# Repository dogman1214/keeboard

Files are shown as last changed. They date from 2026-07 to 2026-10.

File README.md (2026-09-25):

# keeboard

###Note for FORGE Reviewers:
I had already bought the parts for this keyboard. I'm looking for reimbursment, not funding, if that is possible (I beg of thee it is).
I'm sorry that the prices for everything is so high. If you review the BOM, nothing would really be buildable without all the parts I bought. I tried to find the cheapest parts, but I realized that shipping minimum is $8, so then ordering from multiple 3rd party websites, prices would stack up considerably. So then I chose to order from Amazon. Please don't be taken aback by the price, I tried to make it as cheap as possible. The total price was just under $300. 
Please understand why I spent so much. First of all, Trump. Ordering the PCB from JLCPCB costed $45 or so dollars for the bare pcb. Then shipping costs came in, and then also tarrifs. that more than doubled the price to $100, but with the in ap $20 discount I reduced it to $80.
But all these microbumps and macrobumps in price really increased how much I had to spend. Please understand me. I had viewed the budget to be like $180, but it was really concerning how much the price started increasing by. 
PLEASE PLEASE approve this review. I beg of thee. Of courser, changes might need to be made, and I'm fine with that. But on the long term I don't want to lose the money I invested in this project, I did ordered prematurely because Intially I was doing projects via Stardance, but I realized NO WAY i could make deadline. So I swapped to this :) also I know double dipping will get me banned. Don't even tempt me.  I fully swapped over to this.

BY THE WAY, I HAVE ALL THE RECIEPTS AND EVERYTHING SAVED!!! PM me on slack: raghavsharma1214 if you have any inquiries about why price is so high. or just anything.

I'll delete this rant once approved :)

## Overview

This is an ANSI104 layout keyboard. Meaning 100% size, full numpad, and everything. It has creamy gateron milky yellow pro v2 switches, and an esp32 controlling it all. Finally, it is a gasket mount to dampen vibrations, and a silicon pour for the same effect, and to add more weight.  

I created this keyboard because I wasn't really satisfied with the keyboards on the market, and the current keyboard I have now. I want to follow the aesthetic I want, and not some drab boring tech-grey color or whatever, while keeping my own physical case style as well. 

One unique thing i'm proud of is crafting my own Gasket mount system. Instead of using clunky o-ring systems, I designed a brand new board-wide poron tape design. Like foam, it works like a sandwitch above and below the keyboard plate, and designed to provide maximum creamieness.

Editable CAD file: https://drive.google.com/file/d/1waTcEkKPX5QRJGWGog04dOq1EIFDCUFI/view?usp=sharing
Uploading to drive due to the file been 500mb, too large to upload to github.

## Gallery:




## Future Improvements

Optimize the keyboard case design, maybe don't have as many bulky screws. Make the firmware better I guess, minimize latency so that I can game on it. Of course, the keyboard isn't physically built at the moment. 
---

## ASSEMBLY
### ** haven't built yet. Waiting for approval by FORGE **
1. Solder on the diodes and kailh hotswap sockets
2. Solder in the esp32
3. Plug in the switches, with the plate in the middle
4. place PORON foam in the gasket mounts sandwitch style
5. place the plate in between the gaskets
6. place heatset inserts in bottom and screw in m3 screws via the top
7. flash firmware
8. Pour in the silicon pour underneath the PCB, make sure to seal it off with seran wrap first.
9. enjoy!

# Bill of Materials (BOM)

### Electronics & Hardware

| Item | Description | Cost (Pre‑Tax) | Link |
| :--- | :--- | :--- | :--- |
| Switches | Gateron Milky Yellow Pro V2 | $25.90 | https://www.amazon.com/gp/product/B0C2CZJQHT |
| Rotary Encoder | ALPS EC11 THT 20k thread-blue vertical switch (H: 20mm) | $5.58 | https://mouser.com |
| Keycaps | PBT green, MOA profile | $24.99 | https://www.amazon.com/gp/product/B0F914Q43R |
| Diodes | 1N4148 SMD (Qty: 104), SOD‑123 | $0.18/unit | https://www.mouser.com/en/ProductDetail/Diodes-Incorporated/1N4148W-7-F |
| Stabilizers | Durock V3 screw‑in | $25.99 | https://www.amazon.com/dp/B0B2RW12S2 |
| PCB | Custom PCB | $45 | AIVON (with $30 discount applied) |
| Kailh Hotswap Sockets | 120 pcs | $13.20 | https://mechanicalkeyboards.com/products/kailh-switch-hot-swap-socket |
| ESP32‑S3 DevKitC‑1 (N16R8) | MCU | $8.99 | https://www.amazon.com/dp/B0GBT212KM |
| Cyanoacrylate Glue | CA super glue | $5.99 | https://www.amazon.com/dp/B0DYJPW9GK |

### Fasteners & Case Hardware

| Item | Description | Cost | Link |
| :--- | :--- | :--- | :--- |
| M3 Heatset Inserts | Brass | $6.99 | https://www.amazon.com/dp/B0FWWW8VP1 |
| M3 Screws | Assorted set | $6.99 | https://www.amazon.com/dp/B0D3X5CT2J |
| 3D Printed Case | Custom | — | — |
| 3D Printed Plate | Custom | — | — |
| 3D Printed Knob | EC11 compatible | — | — |
| Adhesive Transfer Tape | 3M Scotch 924 ATG | $9.57 | https://www.amazon.com/dp/B00FFDUG9M |

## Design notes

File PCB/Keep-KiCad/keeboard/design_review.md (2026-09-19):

# KiCad Design Review: keeboard

**Project**: keeboard  
**Schematic**: keeboard.kicad_sch  
**PCB**: keeboard.kicad_pcb  
**Analyzer**: kicad-happy v2.2.1  
**KiCad Version**: 10.0  

---

## 1. Power Tree Analysis

### Power Rails Detected
- **GND** — global ground, voltage: 0V (validated)

### Power Source Status ⚠️
- **3.3V rail (U1-3V3-Pad1)**: No declared source detected
  - No PWR_FLAG present
  - No regulator output mapping
  - No bridged solder jumper path to a sourced net
  - **Recommendation**: Add a PWR_FLAG to declare the rail as externally powered, or trace the rail back to a regulator output. If the source lives on another sheet, promote the net name to a global label.

- **5V rail (U1-5V-Pad21)**: No declared source detected
  - No PWR_FLAG present
  - No regulator output mapping
  - **Recommendation**: Add a PWR_FLAG or trace back to power input source.

### Power Flow Summary
The schematic currently has only a global GND net defined. The ESP32-S3-DevKitC's 3.3V and 5V power inputs lack explicit source declarations. For a keyboard with an ESP32-S3, power typically flows from a USB-C connector → voltage regulator → 3.3V/5V rails → ESP32 VCC and component VCC pins. Without a defined regulator or PWR_FLAG, the power tree is incomplete.

---

## 2. Net Tracing Summary

### Overall Statistics
- **Total nets**: 144
- **Total wires**: 327
- **Total no-connects**: 9
- **Unique components**: 218 (7 unique part types by value+footprint)

### Key Matrix Detection ✅
- **6×21 key matrix detected** (104 estimated keys)
- Matches the **ANSI-104** keyboard specification
- **Row nets**: ROW0, ROW1, ROW2, ROW3, ROW4, ROW5
- **Column nets**: COL0 through COL20 (21 columns)
- **104 diodes** (1N4148) connected in the matrix
- **104 switches** (matrix scan switches)

### Rotary Encoder ✅
- **SW1** — RotaryEncoder_Switch symbol present
- Footprint: `Rotary_Encoder:RotaryEncoder_Alps_EC11E-Switch_Vertical_H20mm`
- Also includes stabilizer: **S1** (MX_stab) with footprint `PCM_marbastlib-mx:STAB_MX_2u`
- Quadrature outputs and switch detected

### Wireless Module ✅
- **U1** — ESP32-S3-DevKitC detected
- Wireless type: WiFi/BLE
- Module correctly identified in netlist

### Component Breakdown
| Type | Count | Details |
|---|---|---|
| Diodes (1N4148) | 104 | Matrix common-cathode/common-anode configuration |
| Switches (SW_Push) | 98 | Matrix scan buttons + additional buttons |
| Switches (RotaryEncoder) | 1 | SW1 — rotary encoder with switch |
| Stabilizers (MX_stab) | 2+ | S1, S6 — Cherry MX-style stabilizers |
| IC (ESP32-S3) | 1 | U1 — WiFi/BLE module |

---

## 3. Design Verification

### ANSI-104 Keyboard Layout ✅ CONFIRMED
The key matrix detector found a **6×21 grid** = **104 keys**, exactly matching the ANSI-104 form factor. The row and column nets are properly named (ROW0-ROW5, COL0-COL20) and connected through 104 diodes.

### Rotary Encoder with Switch ✅ CONFIRMED
- SW1 present with RotaryEncoder_Switch value
- Includes both quadrature channels (A/B) and push-button switch
- Stabilizer S1 present for MX-style keycap support

### ESP32-S3-DevKitC ✅ CONFIRMED
- U1 correctly identified as ESP32-S3-DevKitC
- WiFi/BLE wireless module detected
- Pin mapping consistent with DevKitC footprint

### BOM & Sourcing ⚠️
- **0% MPN coverage** — all 7 unique BOM lines missing manufacturer part numbers
- Parts affected: 1N4148 diodes (104 pcs), RotaryEncoder_Switch (1 pc), SW_Push variants (98 pcs), ESP32-S3-DevKitC (1 pc)
- **Recommendation**: Populate MPN fields before fabrication. Use the digikey/mouser/lcsc skills to search by value/footprint.

### Datasheet Coverage ⚠️
- No `datasheets/` directory found
- No BOM parts have MPNs, so no datasheets can be extracted
- **Recommendation**: Run the datasheet sync skill (DigiKey/LCSC) or manually note all claims as "per symbol/library" until datasheets are attached.

### Electrical Rule Check (ERC) ⚠️
The ERC found several violations (see ERC.json), but many are expected for this design:

| Issue | Severity | Notes |
|---|---|---|
| Power pin not driven (#PWR01) | Error | Global power symbol not connected to source |
| CHIP_PU (U1 pin 3) not connected | Error | May be intentionally left floating or requires external pull-up |
| Multiple GPIO pins not connected | Error/Wireless modules often have unused pins |
| ROW/COL labels dangling | Error | Some labels may not connect to the matrix (verify netlist) |
| USB D+/D- not connected | Error | Only needed if USB functionality is used |

**Important**: Many "pin not connected" findings for ESP32 GPIOs are normal — not all 34+ GPIOs need to be connected. The critical ones to verify are: CHIP_PU (enable), USB D+/D-, and the power pins.

---

## 4. Caveats & Known Issues

### High Priority
1. **Power source not declared** — 3.3V and 5V rails lack PWR_FLAG or regulator mapping. The board will not power up without an external power source or regulator circuit.
2. **0% MPN coverage** — Board cannot be fabricated or assembled without manufacturer part numbers. Prototype ordering will fail BOM readiness checks.

### Medium Priority
3. **No datasheets available** — All electrical claims must be qualified as "per symbol/library" until datasheets are attached.
4. **ERC violations** — Several "pin not connected" and "label dangling" findings. Review each: some are expected (unused GPIOs), some need correction (power sources, matrix connections).

### Low Priority
5. **Lifecycle audit not run** — Component EOL/NRND status unknown. Run with `--lifecycle` flag when API keys are available.
6. **SPICE simulation not run** — Requires ngspice/LTspice for behavioral verification of filters, dividers, and the regulator loop.

---

## 5. Recommendations

1. **Add PWR_FLAG symbols** for 3.3V and 5V power rails, or add a voltage regulator circuit with feedback dividers properly connected.
2. **Populate MPN fields** on all BOM parts (104 diodes, 1 rotary encoder, 2 stabilizers, 1 ESP32-S3, push buttons).
3. **Run datasheet sync** using DigiKey, Mouser, or LCSC to download manufacturer specs.
4. **Verify keyboard matrix continuity** — ensure all ROW and COLUMN nets are properly connected to the diodes and switches on the PCB.
5. **Review ERC violations** individually — exempt expected unused GPIO pins, but fix actual power and connectivity issues.
6. **Consider adding a power regulator** (e.g., AP2114 or similar 3.3V/5V LDO) with proper PWR_FLAG if not already present on another sheet.

---

## 6. Overall Assessment

| Category | Status |
|---|---|
| Keyboard Layout (ANSI-104) | ✅ Verified — 6×21 matrix = 104 keys |
| Rotary Encoder with Switch | ✅ Verified — SW1 present with all expected pins |
| ESP32-S3 Integration | ✅ Verified — U1 correctly detected as WiFi/BLE module |
| Power Tree Completeness | ⚠️ Partial — Only GND defined; 3.3V/5V sources missing |
| Net Tracing | ✅ Complete — 144 nets, 327 wires traced correctly |
| BOM Readiness | ❌ Not ready — 0% MPN coverage |
| Datasheet Evidence | ❌ None — All claims per symbol/library |
| ERC Cleanliness | ⚠️ Several findings, many expected for this design |

**Final Verdict**: The design concept is correct — ANSI-104 keyboard with rotary encoder and ESP32-S3-DevKitC is properly schematics. However, **critical power sourcing is missing** and **BOM lacks MPNs** for fabrication. These must be resolved before the board can proceed to production.

---
*Generated by kicad-happy v2.2.1 schematic analyzer*

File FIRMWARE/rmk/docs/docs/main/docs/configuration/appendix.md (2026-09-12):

# Appendix

### `keyboard.toml`

The following TOML contains all available settings in `keyboard.toml`

```toml
# Basic info of the keyboard
[keyboard]
name = "RMK Keyboard" # A label for your configuration; it does not appear on USB or BLE
product_name = "RMK Keyboard" # USB product string and BLE device name, defaults to "RMK Keyboard"
vendor_id = 0x4c4b
product_id = 0x4643
manufacturer = "haobo"
serial_number = "vial:f64c2b3c:000001"
# The chip or existing board used in keyboard
# Either "board" or "chip" can be set, but not both
chip = "rp2040"
board = "nice!nano_v2"
# USB is enabled by default for most chips
# Set to false if you don't want USB
usb_enable = true

# Set matrix IO for the board. This section is for non-split keyboards and is in conflict with the [split] section
[matrix]
# `matrix_type` is optional. Default is "normal"
matrix_type = "normal"
# Input and output pins
row_pins = ["PIN_6", "PIN_7", "PIN_8", "PIN_9"]
col_pins = ["PIN_19", "PIN_20", "PIN_21"]
# RMK uses col2row as the default matrix diode direction, if you want to use a row2col matrix, add `row2col = true`
row2col = false

# Direct Pin Matrix is a Matrix of buttons connected directly to pins. It conflicts with the above.
matrix_type = "direct_pin"
direct_pins = [
    ["PIN_0", "PIN_1", "PIN_2"],
    ["PIN_3", "_", "PIN_5"]
]

# `direct_pin_low_active` is optional. Default is `true`.
# If your pin needs to be pulled up and the pin is pulled down when the button is turned on, please set it to true
# WARNING: If you use a normal matrix, it will be ineffective
direct_pin_low_active = true

# Debouncer mode, "default" or "fast". Default is "default"
debouncer = "default"
# Bootmagic: jump to the chip's USB bootloader when the key at (row, col) is held at boot. Optional
bootmagic = [0, 0]

# Layout info for the keyboard, this section is mandatory
[layout]
# Number of rows. For a split keyboard, this is the total number of rows for all splits
rows = 5
# Number of cols. For a split keyboard, this is the total number of cols for all splits
cols = 4
# keypad example
# ┌───┬───┬───┬───┐
# │NUM│ / │ * │ - │ <-- row 0, col 0..4
# ├───┼───┼───┼───┤
# │ 7 │ 8 │ 9 │   │
# ├───┼───┼───┤ + │
# │ 4 │ 5 │ 6 │   │
# ├───┼───┼───┼───┤
# │ 1 │ 2 │ 3 │ E │
# ├───┴───┼───┤ N │
# │   0   │ . │ T │
# └───────┴───┴───┘
map = """
(0,0,R)  (0,1,R)  (0,2,R)  (0,3,R)
(1,0,R)  (1,1,R)  (1,2,R)  (1,3,R)
(2,0,R)  (2,1,R)  (2,2,R)
(3,0,R)  (3,1,R)  (3,2,R)  (3,3,R)
(4,0,R)           (4,1,R)
"""
# Optional rendered-layout settings, see the Layout documentation page. They only change how
# the keyboard is drawn in Vial/Rynk, never what a key does
# Name of the [[layout.variant]] shown first
default_variant = "full"

# Custom key shapes, referenced as `@name` in `map`
[layout.shapes]
wide_zero = { w = 2.0 }

# Render variants of the same keymap: each hides some keys and reshapes others
[[layout.variant]]
name = "full"

[[layout.variant]]
name = "no_numlock"
hidden = ["(0,0)"]
shapes = { "(4,0)" = "@wide_zero" }

[keymap]
# Number of layers. Be careful, since large layer number takes more flash and RAM
# Optional: defaults to the number of `[[keymap.layer]]` entries. Set it larger
# to reserve extra empty layers (e.g. for editing in Vial/Rynk)
layers = 4

# here are the aliases for the example layer.keys below
[aliases]
MyCut = "WM(X, LCtrl)"
MyCopy = "WM(C, LCtrl)"
MyPaste = "WM(V, LCtrl)"

# Key map definitions per layer:
# The number (and order) of entries on each layer should be
# identical with the number (and order) of entries in `layout.map`.
# Empty layers will be used to fill if the number of explicitly
# defined layers is smaller than the `keymap.layers` setting

# layer 0 (default):
# (the number comes from the order of '[[keymap.layer]] entries' in the file)
[[keymap.layer]]
name = "base_layer" #optional name for the layer
keys = """
NumLock KpSlash KpAsterisk KpMinus
Kp7     Kp8     Kp9        KpPlus
Kp4     Kp5     Kp6
Kp1     Kp2     Kp3        Enter
    Kp0         KpDot
"""
# Per-layer encoder actions, one [clockwise, counter-clockwise] pair per encoder
# defined in [[input_device.encoder]]. Optional: a layer without `encoders` has no encoder actions
encoders = [["AudioVolUp", "AudioVolDown"]]

# layer 1:
[[keymap.layer]]
name = "mouse_navigation" #optional name for the layer
keys = """
TO(base_layer)   @MyCut     @MyCopy          @MyPaste
MouseBtn1        MouseUp    MouseBtn2        MouseWheelUp
MouseLeft        MouseBtn4  MouseRight
MouseWheelLeft   MouseDown  MouseWheelRight  MouseWheelDown
          MouseBtn1         MouseBtn2
"""

# Behavior configuration, if you don't want to customize anything, just ignore this section
[behavior]
# Tri Layer configuration
tri_layer = { upper = 1, lower = 2, adjust = 3 }

# OneShot configuration
one_shot = { timeout = "1s" }

# One Shot Modifiers configuration
one_shot_modifiers = { activate_on_keypress = false, quick_release = false }

[behavior.morse]
# default profile for morse, tap dance and tap-hold keys:
enable_flow_tap = true
prior_idle_time = "120ms"
hold_on_other_press = true
unilateral_tap = false
hold_timeout = "250ms"
gap_timeout = "250ms"

# list of morse (tap dance) keys:
morses = [
  # TD(0) Function key that outputs F1 on tap, F2 on double tap, layer 1 on hold
  { tap = "F1", hold = "MO(1)", double_tap = "F2" },

  # TD(1) Extended tap dance representation for function keys
  { tap_actions = ["F1", "F2", "F3", "F4", "F5"], hold_actions = ["MO(1)", "MO(2)", "MO(3)", "MO(4)", "MO(5)"] },

  # TD(2) Morse code like representation
  { morse_actions = [
      {pattern = ".-", action = "A"},
      {pattern = "-...", action = "B"},
      {pattern = "-.-.", action = "C"},
      {pattern = "-..", action = "D"},
      {pattern = ".", action = "E"},
      {pattern = "..-.", action = "F"},
      {pattern = "--.", action = "G"},
      {pattern = "....", action = "H"},
      {pattern = "..", action = "I"},
      {pattern = ".---", action = "J"},
      {pattern = "-.-", action = "K"},
      {pattern = ".-..", action = "L"},
      {pattern = "--", action = "M"},
      {pattern = "-.", action = "N"},
      {pattern = "---", action = "O"},
      {pattern = ".--.", action = "P"},
      {pattern = "--.-", action = "Q"},
      {pattern = ".-.", action = "R"},
      {pattern = "...", action = "S"},
      {pattern = "-", action = "T"},
      {pattern = "..-", action = "U"},
      {pattern = "...-", action = "V"},
      {pattern = ".--", action = "W"},
      {pattern = "-..-", action = "X"},
      {pattern = "-.--", action = "Y"},
      {pattern = "--..", action = "Z"}
    ], profile = "MRZ" }
]

[behavior.morse.profiles]
# Named overrides of the [behavior.morse] defaults, referenced by name from a morse key
# (profile = "...") or a tap-hold action's optional profile arg — e.g. a home row mod is MT(key, mod, H1).
H1 = { permissive_hold = true, unilateral_tap = true, hold_timeout = "250ms", gap_timeout = "250ms" }
H2 = { enable_flow_tap = false, permissive_hold = true, unilateral_tap = true, hold_timeout = "200ms", gap_timeout = "200ms" }
MRZ = { normal_mode = true, unilateral_tap = false, hold_timeout = "200ms", gap_timeout = "200ms" }

# Combo configuration
[behavior.combo]
timeout = "150ms"
prior_idle_time = "130ms"  # optional, prevents accidental triggers during fast typing
combos = [
  # Press J and K keys simultaneously to output Escape key
  { actions = ["J", "K"], output = "Escape" }
]

# Macro configuration
[[behavior.macro.macros]]
operations = [
    { operation = "text", text = "Hello" }
]

# Fork configuration
[behavior.fork]
forks = [
  # Shift + '.' output ':' key
  { trigger = "Dot", negative_output = "Dot", positive_output = "WM(Semicolon, LShift)", match_any = "LShift|RShift" }
]

# Auto mouse layer: activate a layer on pointing-device motion, see the Behavior documentation page.
# Note the double brackets [[ ]], one entry per pointing device id
[[behavior.auto_mouse_layer]]
# Pointing device id this entry applies to; omit for a fallback that matches any device
device_id = 0
# Layer to activate on cursor motion
target_layer = 3
# Inactivity time before the layer is deactivated, defaults to "500ms"
timeout = "600ms"
# Minimum absolute X/Y delta counted as motion, defaults to 1
threshold = 2
# Deactivate the layer on any non-mouse key press; requires [event.action] subs >= 1
deactivate_on_key = false
# Keys that don't deactivate the layer when deactivate_on_key is set
extra_mouse_keys = ["LCtrl", "LShift"]
# Non-deactivating key presses push the timeout forward
reset_timeout_on_key = false

# Input devices, see the Input Device documentation pages.
# For split keyboards, use [split.central.input_device] / [split.peripheral.input_device] instead
# Rotary encoder; its per-layer actions go in [[keymap.layer]].encoders
[[input_device.encoder]]
pin_a = "PIN_14"
pin_b = "PIN_15"
# Use the MCU's internal pull-up resistor, defaults to false
internal_pullup = false
# Working mode: "default", "e8h7" or "resolution" (then set `resolution`, or `detent` and `pulse`)
phase = "default"

# Analog joystick
[[input_device.joystick]]
name = "default"
pin_x = "P0_31"
pin_y = "P0_29"
pin_z = "_"
transform = [[80, 0], [0, 80]]
bias = [29130, 29365]
resolution = 6

# PMW3610 optical sensor. [[input_device.pmw33xx]] and [[input_device.iqs5xx]] follow the same
# pattern, see their documentation pages
[[input_device.pmw3610]]
name = "trackball0"
# Pointing device id, pairs the sensor with its PointingProcessor and [[behavior.auto_mouse_layer]]. Defaults to 0
id = 0
spi = { instance = "bitbang0", sck = "P0_05", mosi = "P0_04", miso = "P0_04", cs = "P0_09" }
# Motion interrupt pin; omit to poll the sensor
motion = "P0_02"
cpi = 800

# Lighting configuration, if you don't have any light, just ignore this section.
[light]
# LED pins, capslock, scrolllock, numslock. You can safely ignore any of them if you don't have
capslock = { pin = "PIN_0", low_active = true }
scrolllock = { pin = "PIN_1", low_active = true }
numslock = { pin = "PIN_2", low_active = true }

# Output configuration, if you don't neet to set an output pin, just ignore this section.
# Note the double brackets [[ ]], which indicate that multiple outputs can be defined.
[[output]]
# Only the pin name is required, the rest of the fields are optional
pin = "PIN_13"
initial_state_active = false
low_active = false

# Display configuration, see the Display documentation page.
# For split keyboards, use [split.central.display] / [split.peripheral.display] instead
[display]
# Display driver: "ssd1306", "sh1106", "sh1107", "sh1108" or "ssd1309"
driver = "ssd1306"
# Display resolution. Each driver accepts a fixed set of sizes, see the Display documentation page
size = "128x32"
# Display rotation in degrees: 0, 90, 180 or 270. Default is 0
rotation = 0
# Renderer, defaults to the built-in "LogoRenderer"
renderer = "OledRenderer"
# Poll interval in ms for periodic redraws; omit for event-driven rendering only
# render_interval = 33
# Minimum time in ms between event-driven renders, defaults to 33
min_render_interval = 33

# The bus the display is connected to
[display.protocol.i2c]
instance = "I2C1"
scl = "PIN_3"
sda = "PIN_2"
# 7-bit I2C address, defaults to 0x3C
address = 0x3C

# Storage configuration.
# To use the default configuration, ignore this section completely
[storage]
# Whether the storage is enabled
enabled = true
# The start address of storage
# Note: When the `dfu_rp` or `dfu_nrf` feature is enabled, this value is ignored.
# The storage partition is automatically placed after the DFU download slot.
start_addr = 0xA0000
# Number of sectors used for storage, >= 2. Defaults to 8 when a [dfu] section is present, either
# here or in the chip default (nRF52840, nice!nano, RP2040 and Pico W ship one); otherwise 2 unless
# the chip default sets a value. With DFU it cannot exceed the storage partition from rmk-memory.x
num_sectors = 16
# Clear storage at keyboard boot.
# Set it to true will reset the storage(including keymap, BLE bond info, etc.) at each reboot.
# This option is useful when testing the firmware.
clear_storage = false
# Clear the saved layout at keyboard boot, set this to true if you want to reset the layout
clear_layout = false

# DFU configuration (embassy-boot, experimental), see the Bootloader documentation page.
# All fields are optional. Partition offsets are NOT set here — they come from the
# `memory.x` linker symbols generated by rmk-boot.
[dfu]
# DFU activity LED pin ("none" to disable; defaults to "PIN_25" on RP2040, "P0_15" on nRF52)
led = "PIN_25"
# Unlock keys for the DFU lock (requires the `dfu_lock` Cargo feature)
unlock_keys = [[0, 0], [1, 1]]

# Ble configuration
# To use the default configuration, ignore this section completely
[ble]
# Whether the ble is enabled
enabled = true
# BLE related pins, ignore any of them if you don't have
battery_adc_pin = "vddh"
# Optional GATT Battery Level name. Defaults to "Central".
battery_user_description = "Main"
# If the voltage divider is used for adc, you can use the following two values to define a voltage divider.
# For example, nice!nano have 806 + 2M resistors, the saadc measures voltage on 2M resistor, so the two values should be set to 2000 and 2806
# Measured resistance for input adc, it should be less than adc_divider_total
adc_divider_measured = 2000
# Total resistance of the full path for input adc
adc_divider_total = 2806
# BLE tx power; higher means better signal but more power consumption. nRF52 only, ignored on other chips
default_tx_power = 0
# Whether to enable 2M PHY, defaults to true. nRF52 only, ignored on other chips
use_2m_phy = true
# Enable passkey entry during BLE pairing, defaults to false
passkey_entry = false
# Timeout in seconds for passkey entry, defaults to 120, minimum 30
passkey_entry_timeout = 120
# [Deprecated] Pin that reads battery's charging state, `low-active` means the battery is charging when `charge_state.pin` is low
# Input pin that indicates the charging state
# charge_state = { pin = "PIN_1", low_active = true }
# [Deprecated] Output LED pin that blinks when the battery is low
# charge_led= { pin = "PIN_2", low_active = true }

# RMK internal configuration
[rmk]
# Mouse key interval (ms) - controls mouse movement speed
mouse_key_interval = 20
# Mouse wheel interval (ms) - controls scrolling speed
mouse_wheel_interval = 80
# Maximum number of combos keyboard can store
combo_max_num = 8
# Maximum number of keys pressed simultaneously in a combo
combo_max_length = 4
# Maximum number of forks for conditional key actions
fork_max_num = 8
# Maximum number of morse keys keyboard can store (max 255)
# (Each morse key is a programmable multi-tap/hold key)
morse_max_num = 8
# Capacity of the named morse profile table ([behavior.morse.profiles], max 255)
morse_profile_max_num = 16
# Maximum number of patterns a morse key can handle (min 4, max 32; raised automatically to fit the
# largest configured morse key)
max_patterns_per_key = 32
# Macro space size in bytes for storing sequences
macro_space_size = 256
# Default debounce time in ms
debounce_time = 20
# Report channel size
report_channel_size = 16
# Vial channel size
vial_channel_size = 4
# Flash channel size
flash_channel_size = 4
# The number of the split peripherals
split_peripherals_num = 0
# The number of available BLE profiles
ble_profiles_num = 3
# BLE Split Central sleep timeout in seconds (0 = disabled)
split_central_sleep_timeout_seconds = 0
# Maximum macro data bytes in one Rynk macro request or response
protocol_macro_chunk_size = 64
# Rynk RX/TX buffer size in bytes. 488 bytes = 2*BLE maximum packet size
rynk_buffer_size = 488
# Length of one dongle pairing window in seconds. Dongle builds only; repeated
# while no keyboard is bonded, opened once at power-on otherwise
dongle_pairing_window_secs = 30
# Maximum number of [[behavior.auto_mouse_layer]] entries.
# Auto-derived from the number of configured entries when unset
# auto_mouse_layer_max_num = 2

# Event channel configuration.
# Tune the pub/sub channel of a single event type with [event.<name>], where
# <name> is one of: connection_status_change, modifier, keyboard, layer_change,
# wpm_update, led_indicator, sleep_state, battery_status, battery_adc,
# charging_state, pointing, peripheral_connected, central_connected,
# peripheral_battery, clear_peer, dongle_state, dfu_status, action.
# All defaults are in rmk-config/src/default_config/event_default.toml
[event.keyboard]
# Channel buffer size
channel_size = 16
# Publisher waker slots: one per concurrently publishing task
pubs = 4
# Number of subscribers
subs = 3

# Split configuration
# This section conflicts with the [matrix] section. You can only have either [matrix] or [split], but NOT BOTH
[split]
# Connection type of split, "serial" or "ble"
connection = "serial"

# Split central config
[split.central]
# Number of rows on central board
rows = 2
# Number of cols on central board
cols = 2
# Row offset of central matrix to the whole matrix
row_offset = 0
# Col offset of central matrix to the whole matrix
col_offset = 0
# If the connection type is "serial", the serial instances used on the central board are defined using "serial" field.
# It's a list of serial instances with a length equal to the number of splits.
# The order of the serial instances is important: the first serial instance on the central board
# communicates with the first split peripheral defined, and so on.
serial = [
    { instance = "UART0", tx_pin = "PIN_0", rx_pin = "PIN_1" },
    { instance = "UART1", tx_pin = "PIN_4", rx_pin = "PIN_5" },
    # For the RP2040 only, you can also use RMK's Programmable IO (PIO) UART serial port using either or both of the RP2040's two PIO blocks, PIO0 and PIO1, by enabling the RMK `rp2040` feature gate in Cargo.toml.
    # The PIO serial port can be used in half-duplex mode using the same pin for RX/TX
    { instance = "PIO0", tx_pin = "PIN_6", rx_pin = "PIN_6" },
    # Or use the PIO serial port in full-duplex mode using different pins for RX/TX
    { instance = "PIO1", tx_pin = "PIN_7", rx_pin = "PIN_8" },
]
# If the connection type is "ble", we can override the BLE static address used by setting `ble_addr`.
# This address should be a valid BLE random static address, see: https://academy.nordicsemi.com/courses/bluetooth-low-energy-fundamentals/lessons/lesson-2-bluetooth-le-advertising/topic/bluetooth-address/
ble_addr = [0x18, 0xe2, 0x21, 0x80, 0xc0, 0xc7]
# Optional battery ADC config for the central (overrides [ble] battery settings)
battery_adc_pin = "vddh"
# Optional GATT Battery Level name. Overrides [ble] for the split central.
battery_user_description = "Left"
adc_divider_measured = 2000
adc_divider_total = 2806

[split.central.matrix]
matrix_type = "normal"
# Matrix IO definition on central board
row_pins = ["PIN_9", "PIN_11"]
col_pins = ["PIN_10", "PIN_12"]
# Bootmagic key of the central board, in the central's local (row, col). Optional
bootmagic = [0, 0]

# Output configuration for split central (optional)
[[split.central.output]]
# Only the pin name is required, the rest of the fields are optional
pin = "PIN_12"
initial_state_active = false
low_active = false

# Display on the central board (optional), same fields as [display]
[split.central.display]
driver = "ssd1306"
size = "128x64"

[split.central.display.protocol.i2c]
instance = "I2C1"
scl = "PIN_3"
sda = "PIN_2"

# Input devices on the central board (optional), same tables as [input_device]
[[split.central.input_device.encoder]]
pin_a = "PIN_14"
pin_b = "PIN_15"

# Configuration for the first split peripheral
# Note the double brackets [[ ]], which indicate that multiple split peripherals can be defined.
# The order of peripherals is important: it should match the order of the serial instances (if serial is used).
[[split.peripheral]]
# Number of rows on peripheral board
rows = 2
# Number of cols on peripheral board
cols = 1
# Row offset of peripheral matrix to the whole matrix
row_offset = 2
# Col offset of peripheral matrix to the whole matrix
col_offset = 2
# The serial instance used to communicate with the central board, if the connection type is "serial"
serial = [{ instance = "UART0", tx_pin = "PIN_0", rx_pin = "PIN_1" }]
# Override the BLE random static address of the peripheral board
ble_addr = [0x7e, 0xfe, 0x73, 0x9e, 0x66, 0xe3]
# Optional battery ADC config for this peripheral
battery_adc_pin = "P0_02"
# Optional GATT Battery Level name. Defaults to "Peripheral 0", etc.
battery_user_description = "Right"
adc_divider_measured = 2000
adc_divider_total = 2806
# Peripheral firmware for automatic dfu_split updates (requires the `dfu_split` Cargo feature),
# path relative to Cargo.toml. See the Bootloader documentation page
firmware = "./peripheral.bin"
# "MatchHash" (default) flashes only when the peripheral's firmware differs; "force" flashes at every start
update_policy = "MatchHash"

[split.peripheral.matrix]
matrix_type = "normal"
# Matrix IO definition on peripheral board
row_pins = ["PIN_9", "PIN_11"]
col_pins = ["PIN_10"]
# Bootmagic key of this peripheral, in the peripheral's local (row, col). Optional
bootmagic = [0, 0]

# Output configuration, if you don't need to set an output pin, just ignore this section.
# Note the double brackets [[ ]], which indicate that multiple outputs can be defined.
[[split.peripheral.output]]
# Only the pin name is required, the rest of the fields are optional
pin = "PIN_13"
initial_state_active = false
low_active = false

# Display on this peripheral (optional), same fields as [display]
[split.peripheral.display]
driver = "ssd1306"
size = "128x32"

[split.peripheral.display.protocol.i2c]
instance = "I2C1"
scl = "PIN_3"
sda = "PIN_2"

# Input devices on this peripheral (optional), same tables as [input_device]
[[split.peripheral.input_device.encoder]]
pin_a = "PIN_14"
pin_b = "PIN_15"

# More split peripherals (if you have any)
[[split.peripheral]]
# The configuration is the same as the first split peripheral
...
...
...

# Dependency config
[dependency]
# Whether to enable defmt, set to false for reducing binary size
defmt_log = true

# Host-side tools configuration
[host]
# Whether Vial is enabled (default: true in keyboard.toml config)
vial_enabled = true
# Whether Rynk is enabled (experimental, default: false in keyboard.toml config)
# Rynk and Vial are mutually exclusive and must match Cargo features.
rynk_enabled = false
# The unlock keys are the combo of the row 0, col 0 key and
# the row 0, col 1 key. Shared by the Vial lock and the Rynk lock gate.
unlock_keys = [[0, 0], [0, 1]]
# Start (and stay) unlocked. Renamed from `vial_insecure` (still parses).
insecure = false
# Rynk only: move config writes into the locked tier (default: false).
write_requires_unlock = false

# Chip-specific configuration
# To use the default configuration, ignore this section completely
# Use chip-specific sections like [chip.nrf52840] for chip-specific settings
[chip.nrf52840]
# DCDC regulator 0 enabled (nrf52840 only; default: false for chip = "nrf52840" and the XIAO BLE,
# nrfmicro, bluemicro840 and puchi_ble boards, true for nice!nano and nice!nano_v2)
# **Note**: Do not enable DC/DC regulator without an external LC filter being connected
# as this will inhibit device operation, including debug access, until an LC filter is connected.
dcdc_reg0 = true
# DCDC regulator 1 enabled (nrf52840, nrf52833; default: false for chip = "nrf52840" and the XIAO BLE,
# nrfmicro, bluemicro840 and puchi_ble boards, true for nice!nano, nice!nano_v2 and nrf52833)
# **Note**: Do not enable DC/DC regulator without an external LC filter being connected
# as this will inhibit device operation, including debug access, until an LC filter is connected.
dcdc_reg1 = true
# DCDC regulator 0 voltage (nrf52840 only, default: "3V3")
# Valid values: "3V3" or "1V8"
dcdc_reg0_voltage = "3V3"
```

### Available chip names

Available chip names in `chip` field:

- rp2040
- nrf52840
- nrf52833
- nrf52832
- nrf52811
- nrf52810
- esp32c3
- esp32c6
- esp32h2
- esp32s3
- ALL stm32s supported by [embassy-stm32](https://github.com/embassy-rs/embassy/blob/main/embassy-stm32/Cargo.toml) with USB

### Available board names

Available board names in `board` field:

- `nice!nano`
- `nice!nano_v2`
- `XIAO BLE`
- `nrfmicro`
- `bluemicro840`
- `puchi_ble`
- `pi_pico_w`

If you want to add more built-in boards, feel free to open a PR!

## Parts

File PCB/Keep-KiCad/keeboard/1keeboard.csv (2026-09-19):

Id | Designator | Footprint | Quantity | Designation | Supplier and ref
1 | D0, D1, D2, D3, D4, D5, D6, D7, D8, D9, D10, D11, D12, D13, D14, D15, D16, D17, D18, D19, D20, D21, D22, D23, D24, D25, D26, D27, D28, D29, D30, D31, D32, D33, D34, D35, D36, D37, D38, D39, D40, D41, D42, D43, D44, D45, D46, D47, D48, D49, D50, D51, D52, D53, D54, D55, D56, D57, D58, D59, D60, D61, D62, D63, D64, D65, D66, D67, D68, D69, D70, D71, D72, D73, D75, D76, D77, D78, D79, D80, D81, D82, D83, D84, D85, D86, D87, D88, D89, D90, D91, D92, D93, D94, D95, D96, D97, D98, D99, D100, D101, D102, D103, D104 | D_SOD-123 | 104 | 1N4148
2 | SW1 | RotaryEncoder_Alps_EC11E-Switch_Vertical_H20mm | 1 | RotaryEncoder_Switch
3 | SW2, SW2, SW3, SW4, SW5, SW6, SW7, SW8, SW9, SW10, SW11, SW12, SW13, SW14, SW15, SW16, SW17, SW18, SW19, SW20, SW21, SW22, SW23, SW24, SW25, SW26, SW27, SW28, SW29, SW30, SW31, SW32, SW33, SW34, SW35, SW36, SW37, SW38, SW39, SW40, SW41, SW42, SW43, SW44, SW45, SW46, SW47, SW48, SW49, SW50, SW51, SW52, SW53, SW54, SW55, SW56, SW57, SW58, SW59, SW60, SW61, SW62, SW63, SW64, SW65, SW66, SW67, SW68, SW69, SW70, SW71, SW72, SW73, SW74, SW76, SW77, SW78, SW79, SW80, SW81, SW82, SW83, SW84, SW85, SW86, SW87, SW88, SW89, SW90, SW91, SW92, SW95, SW96, SW97, SW98, SW99, SW100, SW101, SW102, SW105 | SW_MX_HS_CPG151101S11_1u | 100 | SW_Push
4 | SW93, SW94, SW103, SW104 | SW_MX_HS_CPG151101S11_1.25u | 4 | SW_Push

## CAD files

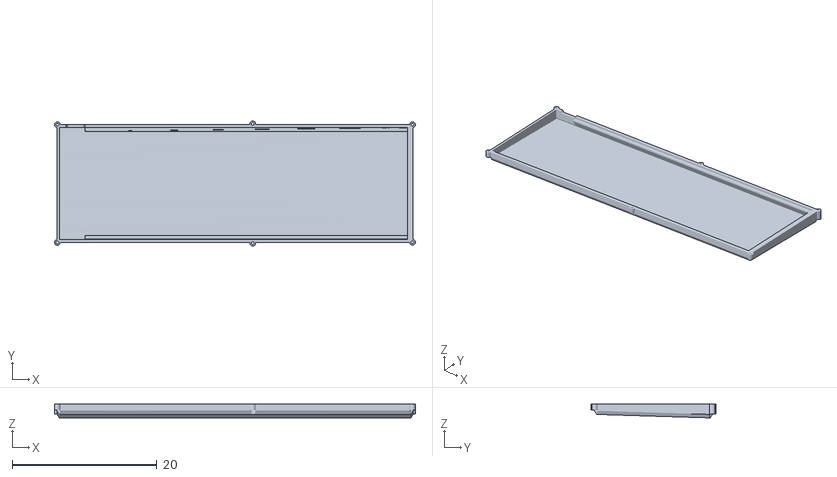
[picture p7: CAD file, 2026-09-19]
CAD/bottompiece.stl
49.8 x 17.3 x 1.92

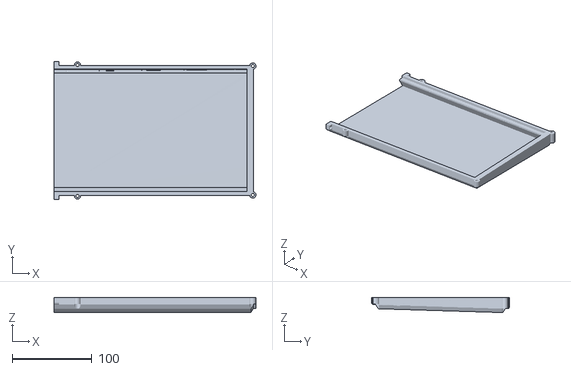
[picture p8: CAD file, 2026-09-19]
production/STL/bottom_left.stl
254.0 x 174.1 x 19.2

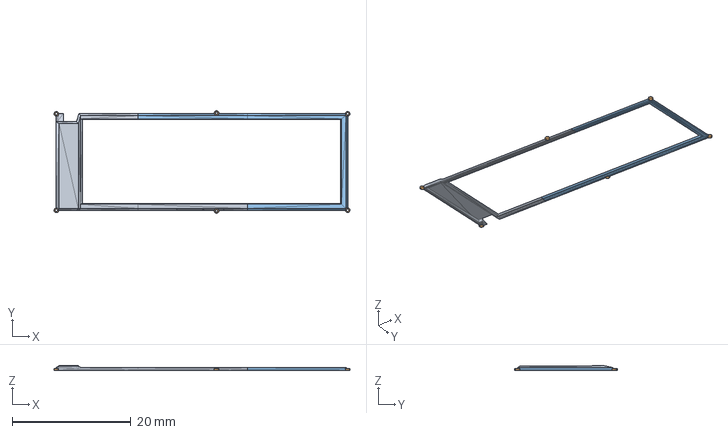
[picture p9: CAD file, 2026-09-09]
production/top.step
49.8 x 17.3 x 0.781 mm

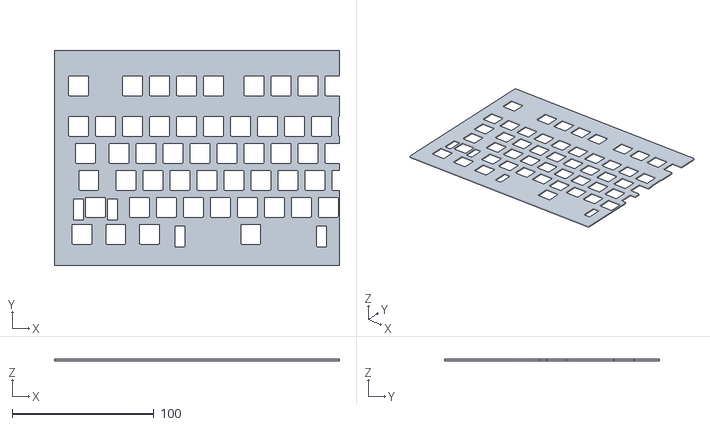
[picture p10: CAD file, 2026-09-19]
production/STL/plate_left.stl
201.1 x 151.5 x 1.50

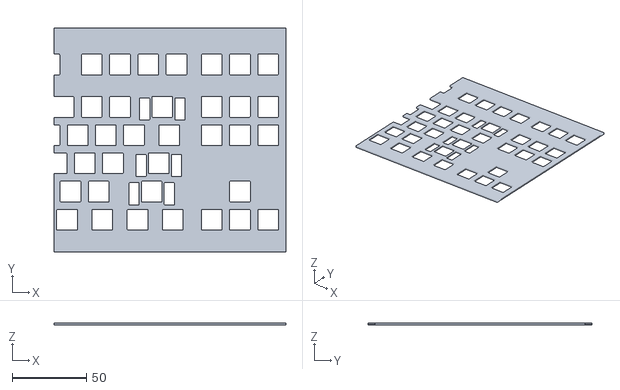
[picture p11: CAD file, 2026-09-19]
production/STL/plate_middle.stl
156.6 x 151.5 x 1.50

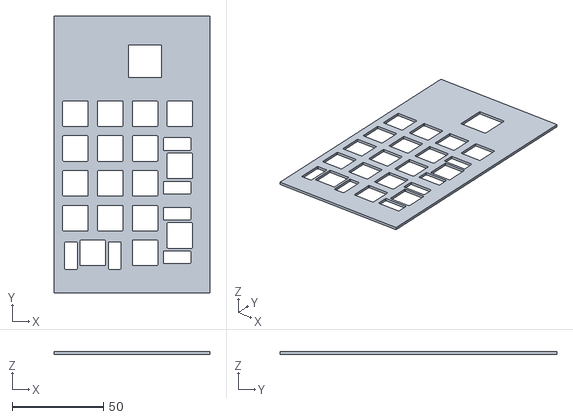
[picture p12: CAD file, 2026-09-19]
production/STL/plate_right.stl
85.4 x 151.5 x 1.50

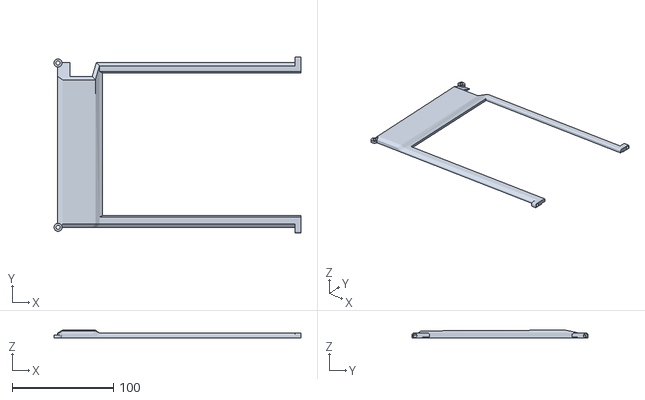
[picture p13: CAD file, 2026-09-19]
production/STL/top_right.stl
243.9 x 174.1 x 7.81

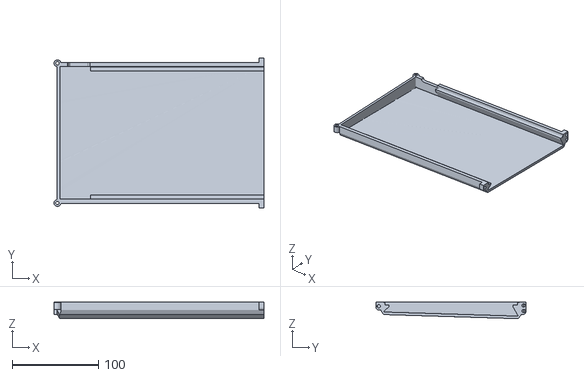
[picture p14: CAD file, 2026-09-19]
production/STL/bottom_right.stl
243.9 x 174.1 x 19.2

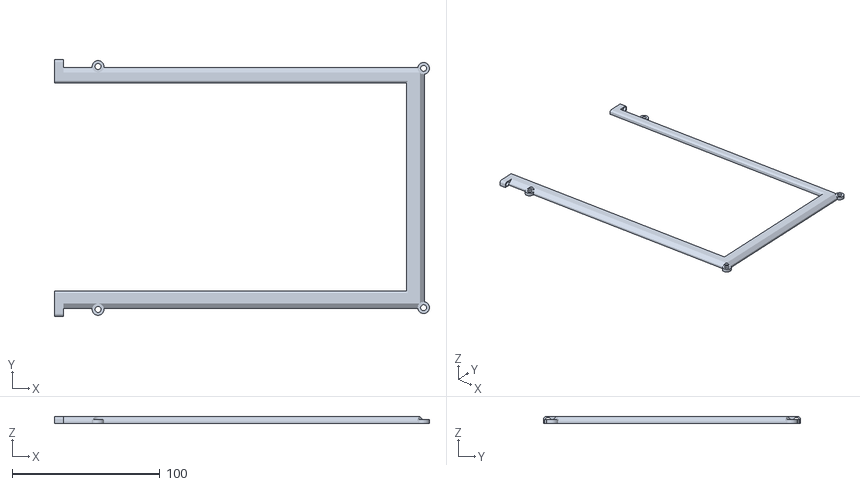
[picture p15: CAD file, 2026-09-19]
production/STL/top_left.stl
254.0 x 174.1 x 4.79

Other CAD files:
CAD/toppiece.stl
production/bottom.step
CAD/Top.step
CAD/Bottom.step
CAD/bottom.stl
CAD/top.stl

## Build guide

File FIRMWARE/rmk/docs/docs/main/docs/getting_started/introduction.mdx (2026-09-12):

# Introduction

RMK is a high-performance and feature-rich keyboard firmware framework, designed for flexibility and ease of customization. RMK leverages the power of Rust and its great async [Embassy](https://embassy.dev/) ecosystem, providing comprehensive and modern functionality across a wide range of microcontrollers.

## Core Features

- **Broad Microcontroller Support**: ESP32, nRF52, nRF54, STM32, RP2040/2350, CYW43(Raspberry Pi Pico W), etc.
- **Wired and Wireless Connectivity**: Offers both wired (USB) and wireless (BLE) connections, with optimized low-power performance and multi-profile support.
- **Simple Configuration**: Configure your keyboard easily through a single [TOML](https://toml.io/) file.
- **On-the-fly Keymap Customization**: Change your keymap in real time via Vial (enabled by default) or RMK's native Rynk protocol (experimental).
- **Advanced Feature Set**: Packed with modern features, including advanced layer management, powerful macros, multi-role key support (e.g., Tap-Hold, TapDance, Morse Key), display support, hardware watchdog and DFU firmware updates.
- **Split Keyboard Support**: Natively supports both wired and wireless split keyboard.

## Next Steps

import { LinkCard } from '@theme'

<div className="grid grid-cols-1 md:grid-cols-2 gap-5">
  <LinkCard
    href="../user_guide/guide_overview"
    title="Tutorial"
    description="A step-by-step tutorial for creating your first RMK keyboard"
  />
  <LinkCard
    href="../features"
    title="Features"
    description="All keyboard features that RMK supports"
  />
  <LinkCard
    href="../configuration"
    title="Configuration"
    description="Explore how to configure your RMK keyboard"
  />
  <LinkCard
    href="https://github.com/rmk-rs/rmk/tree/main/examples"
    title="Examples"
    description="Check the built-in examples for various microcontroller"
  />
</div>

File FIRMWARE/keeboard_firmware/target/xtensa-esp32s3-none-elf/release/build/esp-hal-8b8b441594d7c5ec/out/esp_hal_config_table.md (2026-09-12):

| Option | Stability | Default&nbsp;value | Allowed&nbsp;values |
|---|:---:|:---:|:---:|
| <p>**ESP_HAL_CONFIG_PLACE_SPI_MASTER_DRIVER_IN_RAM**</p> <p>Places the SPI master driver in RAM for better performance</p> | ⚠️ Unstable | false | 
| <p>**ESP_HAL_CONFIG_PLACE_SWITCH_TABLES_IN_RAM**</p> <p>Places switch-tables, some lookup tables and constants related to interrupt handling into RAM - resulting in better performance but slightly more RAM consumption.</p> | Stable since 1.0.0 | true | 
| <p>**ESP_HAL_CONFIG_PLACE_ANON_IN_RAM**</p> <p>Places anonymous symbols into RAM - resulting in better performance at the cost of significant more RAM consumption. Best to be combined with `place-switch-tables-in-ram`.</p> | Stable since 1.0.0 | false | 
| <p>**ESP_HAL_CONFIG_PLACE_RMT_DRIVER_IN_RAM**</p> <p>Places the RMT driver in RAM for better performance</p> | ⚠️ Unstable | false | 
| <p>**ESP_HAL_CONFIG_STACK_GUARD_OFFSET**</p> <p>The stack guard variable will be placed this many bytes from the stack's end. Needs to be a multiple of 4.</p> | Stable since 1.0.0 | 60 | 
| <p>**ESP_HAL_CONFIG_STACK_GUARD_VALUE**</p> <p>The value to be written to the stack guard variable.</p> | ⚠️ Unstable | 0xDEEDBAAD | 
| <p>**ESP_HAL_CONFIG_ENSURE_MAIN_STACK_MINIMUM**</p> <p>Prevent successful build if the main stack is smaller than the configured minimum number of bytes.</p> | ⚠️ Unstable | 8192 | Positive integer or 0
| <p>**ESP_HAL_CONFIG_INIT_STACK_PTR_RANGE_CHECK**</p> <p>Check that the stack pointer is in range during initialization.</p> | ⚠️ Unstable | true | 
| <p>**ESP_HAL_CONFIG_STACK_GUARD_MONITORING**</p> <p>Use a data watchpoint to check if the stack guard was overwritten.</p> | ⚠️ Unstable | true | 
| <p>**ESP_HAL_CONFIG_STACK_GUARD_MONITORING_WITH_DEBUGGER_CONNECTED**</p> <p>Enable the stack guard also with a debugger connected. Also applies to `write-vec-table-monitoring`.</p> | ⚠️ Unstable | true | 
| <p>**ESP_HAL_CONFIG_IMPL_CRITICAL_SECTION**</p> <p>Provide a `critical-section` implementation. Note that if disabled, you will need to provide a `critical-section` implementation which is using `restore-state-u32`.</p> | ⚠️ Unstable | true | 
| <p>**ESP_HAL_CONFIG_INSTRUCTION_CACHE_SIZE**</p> <p>Instruction cache size to be set on application startup.</p> | ⚠️ Unstable | 32KB | One of:<br/><ul style="display: inline-block; text-align: left"><li>16KB</li><li>32KB</li></ul>
| <p>**ESP_HAL_CONFIG_INSTRUCTION_CACHE_LINE_SIZE**</p> <p>Instruction cache line size to be set on application startup.</p> | ⚠️ Unstable | 32B | One of:<br/><ul style="display: inline-block; text-align: left"><li>16B</li><li>32B</li></ul>
| <p>**ESP_HAL_CONFIG_ICACHE_ASSOCIATED_WAYS**</p> <p>Instruction cache associated ways to be set on application startup.</p> | ⚠️ Unstable | 8 | One of:<br/><ul style="display: inline-block; text-align: left"><li>4</li><li>8</li></ul>
| <p>**ESP_HAL_CONFIG_DATA_CACHE_SIZE**</p> <p>Data cache size to be set on application startup.</p> | ⚠️ Unstable | 64KB | One of:<br/><ul style="display: inline-block; text-align: left"><li>32KB</li><li>64KB</li></ul>
| <p>**ESP_HAL_CONFIG_DATA_CACHE_LINE_SIZE**</p> <p>Data cache line size to be set on application startup.</p> | ⚠️ Unstable | 32B | One of:<br/><ul style="display: inline-block; text-align: left"><li>16B</li><li>32B</li><li>64B</li></ul>
| <p>**ESP_HAL_CONFIG_DCACHE_ASSOCIATED_WAYS**</p> <p>Data cache associated ways to be set on application startup.</p> | ⚠️ Unstable | 8 | One of:<br/><ul style="display: inline-block; text-align: left"><li>4</li><li>8</li></ul>
| <p>**ESP_HAL_CONFIG_MIN_CHIP_REVISION**</p> <p>The minimum chip revision required for the application to run, in format: major * 100 + minor.</p> | ⚠️ Unstable | 0 | 
| <p>**ESP_HAL_CONFIG_USE_RWDATA_LD_HOOK**</p> <p>Include 'rwdata_hook.x'</p> | ⚠️ Unstable | false | 
| <p>**ESP_HAL_CONFIG_USE_RWTEXT_LD_HOOK**</p> <p>Include 'rwtext_hook.x'</p> | ⚠️ Unstable | false | 
| <p>**ESP_HAL_CONFIG_CLEAR_CRYPTO_SECRETS**</p> <p>Clear secret material (keys, exponents, intermediate results) from the crypto accelerator registers after each operation. Disabling this leaves secret material in the peripheral until a subsequent operation overwrites it.</p> | ⚠️ Unstable | true | 
| <p>**ESP_HAL_CONFIG_USE_XTAL32K**</p> <p>Enable the external 32 kHz crystal (XTAL32K). When enabled, LP/RTC slow clock defaults to the crystal, XTAL32K is powered at init, and the dedicated crystal GPIO pins are removed from `Peripherals`. Do not use those pads for GPIO, ADC, LP, or any other function (including via `steal` / `AnyPin`) while the crystal is active. When disabled (default), XTAL32K stays off so those pins can be used as hi-Z GPIO.</p> | ⚠️ Unstable | false |

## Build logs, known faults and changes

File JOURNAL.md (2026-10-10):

---
title: "KEEBoard"
author: "Raghav Sharma"
description: "A custom mechanical keyboard designed for maximum thoccieness"
created_at: "2026-07-18"
---
# 7/18/2026: Setting up and Schematics:
This entry incloudes the setup fo the github, planning parts, size of the keyboard, and starting the schmatics in KiCad.

The schematic required a lot of copy and pasting, since it required ~100 combinations of keys and diodes and all of that sort of stuff.

I had to learn that we needed diodes, which specific ones (1n4148), keyboard layout sizes (100%, 60% etc..) and whatnot. Basically made myself familiar with everything in this project ,and also made the schematics.


did annotating schematic and all, assigned footprints and all (made sure the switches are kailh hotswap socket)
Next steps would be the pcb design. Will get really messy lmao.

**Total time spent: 4.2 hours**

# 7/19/2026: PCB took a lot of time
Setting up the PCB took hella time. I also changed the schematic. The layout i used to have was very cursed and had a semi-numpad so I changed it to have a normal numpad or something like that. SO now its like an 104 key thing layout. Has a baby numpad and also a numpad.
I also had to change the motherboard thing to a Teensy 4.1, then changed to an esp32-S3 because the teensy doesn't have a USB-C port, because I dont have enough gpio pins to accomodate all the keys (just 1 row short), even when using matrix wiring

The problem is that the PCB's keys are all jumbled up. I have to arrange the keys, in a specific order according to matrix wiring, locate which key to put where, space it properly with stabilizers, etc etc. It was SO SO SO DAMN Annoying!!!!

I spent so long doing all this that I got kind of pissed off its legit 2:14 AM rn



**Total time spent: 8 hours**

# 7/21/2026: Editing schematics
Today I started off by finishing the schamtic. Assigned all the columns rows and thingamajigs to the ESP32 S3, and ddi the footprint assigning. (REALLY REALLY ANNOYING SINCE I FOUND OUT YOU HAVE TO SPECIFY WHICH TYPE OF SWITH< THE SIZE OF THE SWITCH & THE SIZE OF THE STABIIZER AND ALL.)

Then I realized THE ESP32 S3 WONT EVEN BLOODY WORK! IT DOESNT HAVE ENOUGH GPIO PINS THAT WORK> APPARENTLY I CAN"T USE THE GPIO PINS 0, 3, 45, 46 WHICH IS BLOODY WIERD WTF DUDE.

BUT WAIT! I failed to account for the BLoody DIODES!!!!!!! HAHAHAHHhahahaHAHAHAHAHA THE DIODES MAKE IT WORK IVE BEEN RUNNING IN CIRCLES FOR NOTHING LMAOOOOOOOOOOOOOOOOOOOOOOOOO

I added more stabilizers btw for what I need (7 in total).

The footprint assigning I used AI to help me know what keys in the ANSI 104 layooutneeded big stabs or big keys.

big jumpble.

---- LATER ON ---
In the schematic I had used the generic esp32-s3 schematic, just the chip itself, so there wasn't a footprint for it. So I had to replace it with the esp32-s3 devkit c1, which had the actual board, and had to re=assign all the connections to that. took a decent amount of time since there were so many wires to route. But I now fixed all the footprints and all and am transitioning to pcb design.

Edit: I ran ERC and realized I had placed the labels wrong. I placed the labels above the wires, when I was supposed to place it's square ON the wire so it registers its connected to it. Now I gotta move all the labels. >:( I also have to trim the wiring and all to fit. I lowk did a bit sloppy so making it more neat. I also have to add the no-connection flags and all.


BTw now getting on with some Deeeelicious PCB stuff

https://lapse.hackclub.com/timelapse/3WUqAu4O8yRH
https://lapse.hackclub.com/timelapse/WA8jEyx22OIn
**Total time spent: 4 hours**

# 7/22/2026: PCB stuff hell yeah!
I setting up pcb and all, ordering in the locations and stuff; it's taking quite a while but i'm doing it. I made some schematic changes to fix DRC and ERC but nothing major. I just found out the esp32-s3-Devkit-c has 2 usb-c ports which is kind of dumb lmao. Idk whether I should keep in the render

yeah just a lot of moving going on rn
https://lapse.hackclub.com/timelapse/CDYBX5rDsyJH
**Total time spent: 3.4 hours**

# 7/22/2026: Working on PCB lines
Right now, I'm experiencing a few conflicts in the design stuff. first off all, there are multiple versions of the 1n418 diode. one is THT other is on the wall or whatever (w). THT diodes are massive, so I wanna use the tiny 1n4148w diodes instead will be much better. Yes, better yes. Used the D-sod-123 diode footprint.

So now I set it as that, we have to go onto th wiring thingamajigs.

But i realized, the diodes are in the wrong location. I am wiring them to pin two, not one, so now I have to move all the diodes to their respective locations.

I was wondering, How would I go about wiring the PCB routes and make the wires not intersect, since they are in a matrix type of wiring. But then I realized, I acn use the top of the pcb for the rows and bottom for the columns, or vice versa.

I flipped all the kailh hotswap ports onto the back.

I also made a kinda du mb mistake, i routed the tracks to the soder points which were on the oppsoite side of the keyboard lmao.

Huh... something wierd happened wiht my key placement & wiring

I have an extra key idk how did this happen but the keyboard layout is normal. Things are funked out what?

nvm it was the esc key i had forgotten.

I finished the column wiring..


https://lapse.hackclub.com/timelapse/9pfG5WRcHhSc
**Total time spent: 4.03 hours**

# 7/26/2026: Row wirint etc...
Now I'm doing the row wiring... Also I forgot a diode on the esc key so I'm adding that.

there was sme funky thing about obstacle avoidance, so i had to manyally avoid those obstacles.


https://lapse.hackclub.com/timelapse/O9weNJ8J25Oj
**Total time spent: 1.5 hours**

# 7/31/2026: wiring n stuff
The wiring to the actual gpio pins is getting hella hella cursed like I cannot describe how much.

the layout of the footprint vs in the schematic is far different, so the wires are getting all jumbled. I'm also wiring with alternating directions kind of to make this a tad bit simpler.

Once I was drebugging this connection where I was missing a column but I had just wired 2 gpio pins to one column it was so dumb lmao

Next gunna start validation of pcb.
I legit took an hour tryig to fit column wires to the gpio pins cuz the gpio pins are not LABELED IN FLIPPING order!!! So its like trying to navigate a maze.

https://lapse.hackclub.com/timelapse/npw5BTYCQf9S
https://lapse.hackclub.com/timelapse/O9weNJ8J25Oj
**Total time spent: 3.1 hours**

# 8/1/2026: I just realized...
I js realised that I didn't wire up the diodes to the key. I gotta do that for every single damn key.


Now I gotta wire the rotary encoder.

And then, I realized again that I have an extra column, so I have to assign that to a spare gpio port. A bit messy. I wired it to gpio 16. The only problem is that I have two paths now, fix all the rows and rewire evverything, or accept it'll get a bit messy and then make the code a bit , a tiny bit unintuitive. I'm going with the second one.

So this is how the overall pcb looks like rn:

then, ii realized that the edges of the pcb are too wide. so I'm trimming it down to 7mm thick edges, while also adjusting the wires as well for it.

So now that I double chekced the tracks and all, I think now its time for the case design!

**Total time spent: 3 hours**

# 8/1/2026: it is NOT time for case design.
I'm mopping more things up on the pcb; one major problem was how close some wires/routes are to each other. It gets a bit sketchy, so I'm making it a bit more roomy. I don't know what are the error bounds of the pcb manufacturer I'll order from, soI would rather be safe then sorry. Then I manually inspect eveyrrthing double triple diple check


this section was hella close to each other, so I kind of adjusted it a bit for it to be a bit more roomy.

**Total time spent: 0.4 hours**

# 8/7/2026: Starting the case fr
I'll start the case design in freeCAD, then transition to blender for the final stuff. Kicad is good for like measurements n stuff, but I'm used to blender so I think I should finish up with that with final touches and cosmetic additions.

OOOÓ MYYYYY PCCCCCC

THE BLOODY STEP FILE INCORPORATGED EVERY SINGLE MOLECULE AS AN INDIVIDUAL PART

ITS LAGGING MY PCCC

wait what

why is edge taking all my resources wtf its not freecad

so I hid all the tiny solderparts and kept the green pcb thingy visible for now only.

so what I want to do is that not make the case 3d printed, but like that is probably the way to go with a translucent look.

Okay. so starting out with modeling, cuz this is a gasket mount, it is different then the usual 3d design. I want to add foam padidng underneath the keyboard to make it sound thoccy..

The whole design should follow this analogy or something idk:


(just use one piece of foam no need for a billion layers though)

I like this kind of aeshtetic for the colros:

or maybe this:

wait though. I forgot to assign 3d models to each footprint in kicad. Sigh

Ugh. Anyway, I'm planning possible I could order the keyboard case to be CNC'ed out of wood. that would be fun and thoccy.

https://lapse.hackclub.com/timelapse/O9weNJ8J25Oj

**Total time spent: 4 hours**

# 8/8/2026: Making more case stuff
Okay so now I legit started making the case and all. Yeah it is going to be wood CNC'ed for extra thoccyness.

ooh yeah we gettin somehwere





So I chatted with a dude on slack about this whole timing thing, and he said that it is better to do timelapses, so taht's probably what I will do.

Yeah so I logged just 40 min of ts.

But like, doing wood cnc is unlikly cuz it costs way too much. I'm confused.
https://lapse.hackclub.com/timelapse/TtJ4D92b5bW6
**Total time spent: 2 hours**

# 8/14/2026: Importing from macondo
Transitioning from Macondo
I realized that I won’t be able to complete this project in time for macondo, so, instead I will do the project here!
All the logs for the creation process are on macondo, I can provide as per request, but I’ll be continuing off of here.


**Total time spent: 0.1 hours**

# 8/14/2026: PCB design
Changes, and advancements in pcb design…
I decided that i will use a top-mount case, much easier to manufacture than gasket mount, which I am alien to… kind of.
What I’m doing is kind of a combination of top mount case and gasket mount. I will use a foam tape as a sort of gasket type thing, but it will span the entire perimeter of the keyboard, instead of specific gasket areas, allowing me to get a proper thocky sound but at an easier way to design it.
I’m also placing all the keys now for visual representation.


**Total time spent: 1.45 hours**

# 8/15/2026: Finished placing keyboards
Finished placing the keys, a daunting task.
I had to manually place the keys, reference what the offset is compared to otehrso n the guide, etc etc.
And get this: It is all just for the visual cad represenation when this finishes.
lmao

https://lapse.hackclub.com/timelapse/Dbg5_lDgB0Mr
**Total time spent: 1.5 hours**

# 8/15/2026: Going to blender
Now I’m transitioning to blender for the case design. I like blender because I can fine tune the aesthetics and all.
SO I set up the case basics and everything, like the outline of the case, dividing into two parts. Very roguht right now. it looks pretty nice. I used a pre-designed set of keycaps online because I won’t be making those, but ordering them instead. anyway, it all looks pretty nice!

https://lapse.hackclub.com/timelapse/u7cj53Iw6BM7
**Total time spent: 1.6 hours**

# 8/15/2026: Making the case look nicer
Working on the keyboard case…
I made the exterior look all nice (ish), but I didn’t create the semi-gasket mount. An invention of my own
The “gasket” is just foam tape going around the whole perimeter of the keeb’s plate. Absorbing vibrations and enhancing “thoccieness”
Hell yeah
I still have to finish the case. It isn’t close to being done yet. This is a rough “sketch”


https://lapse.hackclub.com/timelapse/davr5KGs2haT
https://lapse.hackclub.com/timelapse/O-nzzSRrc6XQ
https://lapse.hackclub.com/timelapse/pFWcI6FXZqfJ
**Total time spent: 2.8 hours**

# 8/16/2026: redesigned the bloody case
Okay so I swapped up the case design agian. I had to redesign eveyrthing because the top part of the case is too shallow for the esp-32 s3.
Also I have to make sure the walls have thickness right now they are just 0mm thick.
BTW, what i’m doing in this keyboard case, is something rarely done before. I’m creatign a gasket mount but no the regular kind. THis one will consist of poron foam tape spanning the entire perimeter as the “gasket”

https://lapse.hackclub.com/timelapse/vjpRqQFbX-ZC
**Total time spent: 2.15 hours**

# 8/16/2026: making more parts of the keyboard case
building even more of the case
I finished up the general shape of the case. I created an opening for the USB-C port, and now I have to give the walls actual thickness and stuff, and check for stuff. This case design is really cursed because instead of combining two walls, I just placed the verticies in the same place instead of joining lmao

**Total time spent: 1.5 hours**

# 8/16/2026: stukkyy wukkky
My design is cooked…
The plate is same in dimensions as the PCB, so there is no way for the gasket support to fit between PCB and plate without losing structural integrity or just not fitting if I’m 3d printing. So I think the workaround here is to widen the plate across the y-axis and use those protrusions as support for the gaskets.
Idk I’ll see how the flow goes lowk.
Even though right now it is a kind-of gasket mount, this classifies it as a semi kind-of gasket mount lmao
Also, I’m deciding that I will do a silicon pour under the PCB for maximum sound insulation. it will also add weight to the keyboard, to keep it anchored and NOT rattly.
next will be to double check all parts of keyboard, make sure everything has proper thickness, and hope for the best!

https://lapse.hackclub.com/timelapse/UB852jE3cXXg
**Total time spent: 1.5 hours**

# 8/18/2026: Hopefully finalized design.
I finalized the keyboard design (hopefully…)
I added sections for rubber feet
Made the case slightly longer for the bottom to have some thickness, and all sorts of other stuff. Now onto rendering or sum idk.


Okay so I'm rlly sorry but I'm trying to add lapse links but I'm lost since my stupid ass named then as random ass things. So things are rlly jumbled and idk where to add them.
https://lapse.hackclub.com/timelapse/zuQVrlLpvVih
https://lapse.hackclub.com/timelapse/dT5T0_WiVqiY
https://lapse.hackclub.com/timelapse/7iLm_rG60SL7
https://lapse.hackclub.com/timelapse/o11d3SUkNIfR

**Total time spent: 1.2 hours**

# 8/18/2026: Rendering
Doing the rendering. Changing the keyboard colors and everythign and making them look nice. pretty annoying, tried to color mach from keychron website.

https://lapse.hackclub.com/timelapse/o11d3SUkNIfR
**Total time spent: 0.5 hours**

# 8/19/2026: working more on rendering
Places a lot of objects and set up scene + lighting. changed keyboard colors a bit, working on camera placement and everything

https://lapse.hackclub.com/timelapse/5ryYk5S8lQw_
**Total time spent: 1.55 hours**

# 8/21/2026: Completed final render
Did all the final rendering stuff, set up a custom camera with custom lens simulations and everything. had to render mulltiple time si had these weird white lines coming through whihc i had to solve (just deleted them...)

https://lapse.hackclub.com/timelapse/4kv4oGFfk9Vz
**Total time spent: 3.2 hours**

# 8/23/2026: Working on the parts and everything
I forgot to put screw holes i just remembered. will havve to do that but i was researching what parts to use and everything (like gateron milky yellow v2 for switches) and everything. 

https://lapse.hackclub.com/timelapse/J7ylp05SC9PL
**Total time spent: 1.7 hours**

# 8/23/2026: Fixing some things and adding hole designs.
Blender kept freezing though. Maybe i'll do it tomorrow if my laptop has a good day. But i'm attempting to create holes for screws and everything.

https://lapse.hackclub.com/timelapse/NQN4vzMRkYzO
**Total time spent: 0.7 hours**

# 8/27/2026: Able to work on holes actually
I removed the bazillion verticies that were frying laptop. Used remesh mod for that, but topology got messed up. Its fine thouhg, 3d printing will smoothen it out. Bit im a bit conflicted about the holes.

https://lapse.hackclub.com/timelapse/v0PyT1fEGhM-
https://lapse.hackclub.com/timelapse/1eI4YYaWjZMA
**Total time spent: 1.7 hours**

#8/30/2026: Finishing the screws
I had to add independent screw holes and everytihg. pretty annoying since i had to like use boolean cut on a billion cylinders then anotehr subset of cylinders then more blah blah blah. I didn't like this parto ne bit.

https://lapse.hackclub.com/timelapse/1QoecTHTxuNr
**Total time spent: 1.5 hours**

# 9/7/2026: Big gap, bu did conversion and mesh combinging.
Polishing the keyboard.
I converted the STLs to .STEP (a very annoying process btw), but before that i had to optimize the whole thing. I had to combine meshes and everything because all the files were totaling ~1g, and frying my RAM. Also I continued creating the BOM, and validating the PCB and stuff. This was SOO slow. because my ram was maxed out, I had to use SWAP. then blender, i had to wait like ~15 minutes between each operation because it ran hella slow. But I started researching different things like which keycaps I should use, which pour, and whatnot. BUt the whole optimization was so freaking tedious it took my whole bloody afternoon

https://lapse.hackclub.com/timelapse/s4NLWLckjnWW
https://lapse.hackclub.com/timelapse/9wDRVpnykdvd
**Total time spent: 6 hours**

# 9/10/2026: Working on the BOM and github
Working on the keyboard and BOM.
I decided to remove small ledges underneed the keyboard case for the rubber stoppers. I can just glue them on underneath. Having those ledges just gives the chance of messing up the 3d print. So I’ll do it like that. Also, I’m working on the github. I am solidifying the whoel readme and BOM

https://lapse.hackclub.com/timelapse/lrfo8aeNaO_v
**Total time spent: 2.1 hours**

# 9/13/2026: Major redesign
righty guys so i changed some PCB things, sorted out through budget (was pushing $300 but now down to 220) and I split the prints in half so that they can actually be printed. I had to create brand new screw holes and patch existing holes and stuff with cursed geometry, like i had to add more screw holes to attach both side togehter, because i realized i couldn't print a whole 500mm keyboard case at once, so thats pretty cursed.

https://lapse.hackclub.com/timelapse/fAKmIf1tENd9
https://lapse.hackclub.com/timelapse/TGsbc-rKLcf3
https://lapse.hackclub.com/timelapse/iEL3SugmyFE-
https://lapse.hackclub.com/timelapse/JbOWPj8l-TUY
https://lapse.hackclub.com/timelapse/1CyQhn8J4snw
https://lapse.hackclub.com/timelapse/meIdq8h9bs9P
https://lapse.hackclub.com/timelapse/fT-6s93iyEma
**Total time spent: 9.5 hours**

# 9/14/2026: Gunna order parts
I just wrapped up some things, teaked the case design (removed some wierd ass bezels and stuff) and then chopped the plate into one more piece so i can print it laying flat down. because the case is oging to be printed vertical, but not teh plate.

https://lapse.hackclub.com/timelapse/KHnGpdSAQRNY
https://lapse.hackclub.com/timelapse/_tLt5n1YfoyA
**Total time spent: 2.1 hours**

# 9/24/2026: Soldering parts
I have now finished soldering the Kailh Sockets. This was a genuine pain in the bum. First, I had to experiment soldering on another PCB, since I recieved 5 in total, and then found out a strategy to solder the sockets. First, I soldered the left pad by itself, then aligned the socket and heated up that pad to join the socket. Then I soldered the empty socket when its jammed in place, so nothing moves. Wierdly effective, but time consuming. I had to do everything one by one. Place on ething, solder the pad, solder the first socket, solder other side, rinse and repeat. One. Hundred. and Four times. Genuinely took forever smh. I'm genuinely concerned about how I'll do the teensy weensy tiny SMD diodes since I only have a blunt soldering tip and a thick soldering wire with rosin. 


https://lapse.hackclub.com/timelapse/H5k_-UeXBgWG
https://lapse.hackclub.com/timelapse/zRzu4sp40AVt
https://lapse.hackclub.com/timelapse/RmOGKjhCM0rE
https://lapse.hackclub.com/timelapse/noeTP2a9b3Nx
https://lapse.hackclub.com/timelapse/yzeAAGhjt6hX
**Total time spent: 5 hours**

# 9/26/2026: Working on the Tiny diodes
Now I have to start working on the tiny diodes. They are EXTREMELY TINY. a GENUINE PAIN TO DO! The freakign soldering tip is wider than the diode itself. How am I gunna do this!

https://lapse.hackclub.com/timelapse/0-csvNaUK8Cf
**Total time spent: 1 hour2**

# 9/29/2026: Still working on the diodes.
Yes, they are extremely small. The work is very boring and annoying. my eyes lowk hurt right now, but gotta keep soldering.

https://lapse.hackclub.com/timelapse/fJLRelDF6R2u
**Total time spent: 2 hours**

# 9/30/2026: FINISHED DIODES LESGOO

I finished the diodes! I finished soldering those tiny little bastards and completed a voltage check on each to see that its all good. 
I first soldered the top of the pad, then put on the diode and osldered the top of the diode in, and then sodlered the bottom so it don't move. A lengthy and painful process but yeah...
Lmao so the lapse goes dark sometimes because I'm working in the garage, and it has a motion-operated light. So every 7 minutes the light turns off and I have to stand up to turn it back on.

https://lapse.hackclub.com/timelapse/D_39pcSAa2Mo
**Total time spent: 2 hours**

# 10/2/2026: Oh my god the esp32

So funny thing, the esp32 that I have is too wide somehow. Even though i ordered the esp32 according to teh footprint. So I had to do some really wierd things.

Look, its off.
SO Ihad to bend the pins. 

ANNNNND THEN hammer it in (kind of, with the butt of a screwdriver) so that the esp32 would fit in these bent pins.
and voila: 
I don't like this arrangement a single bit.
https://lapse.hackclub.com/timelapse/m88__-mdD0b6
**Total time spent: 1.6 hours**

# 10/6/2026: Researching firmware
The firmware I have in my git is hella messy and prolly won't work with my keyboard.
So I did a LOT of digging around, searching what firmware is best and how to set it up and everything.
Right now, my main contenders are RMK and QMK. RMK is excellent for stuff like split keyboards as well.
BUt I have a normal keyboard, and lowk the differences in latency and all won't be a big difference.
I found a think called QMK configurator, hella neat, prolly gunna speed up my firmware process and all. nice.


https://lapse.hackclub.com/timelapse/hlJvCyuOXY1m
**Total time spent: 2 hours**

# 10/8/2026: Finished stabilizers+switches+keycaps
pretty major step forward. I was free pretty much all day, and did this over a couple days. I soldered in the rotary encoder. Then, I screwed in the stabilizers. Now, the wierd part was putting on the switches. Because the switches are what keeps the plate attached to PCB and vice versa, first I plug the switches into the plate, and then insert the hella bunch of switches into the PCB, which is no easy task. I have to literally hold it and squeeze it like how you pray, and then do that a billion times to make sure connection all good. And then,,, I had to put on the keycaps. I love these keycaps. Testing the sound is very positive. Relatively thoccy for now. But I didn't set up gasket n all. One funky thing was the space key was very damped and didn't spring back up. I found out the stabilizer's rod was too long, so I bent the tips so It would fit better. And the whabam! fixed. I tested it with the 3d printed case, all positive. (Btw I 3d printed case at school). 


https://lapse.hackclub.com/timelapse/BpTJ6pcCB4ku
https://lapse.hackclub.com/timelapse/B4OU2ahvuMW4
https://lapse.hackclub.com/timelapse/KgMDGSmmF9WN
**Total time spent: 2.5 hours**

# 10/9/2026: Putting in the heatsink screw stuff and PORON gaskets.
So I put in the heatset insers or whatever, went pretty well I burnt my finger. But I put the heatset inserts into the part of teh bottom case where I already have the top part printed as well. So I'm still waiting for the second part of the top part of case to be printed to complete that part. Then, I started doing poron gasket cutting and gluing. So the poron strips have to be like 5mm wide and like 500mm long, so initially i traced an outline with a Xacto knife then cut it with a scissor. It was very NOT straight, but after gluing it onto the dedicated slots in the case, and putting the plate with PCB on top, it sounds AMAZING!! Very creamy and thoccy. Although there is a bit of flex in the plate since it's 3d printed. But thats where the silicone rubber will come into rescue, it'll help support the pcb so the plate won't have that much flex. 

https://lapse.hackclub.com/timelapse/lYwlrxZDCaxK
**Total time spent: 2.2 hours**

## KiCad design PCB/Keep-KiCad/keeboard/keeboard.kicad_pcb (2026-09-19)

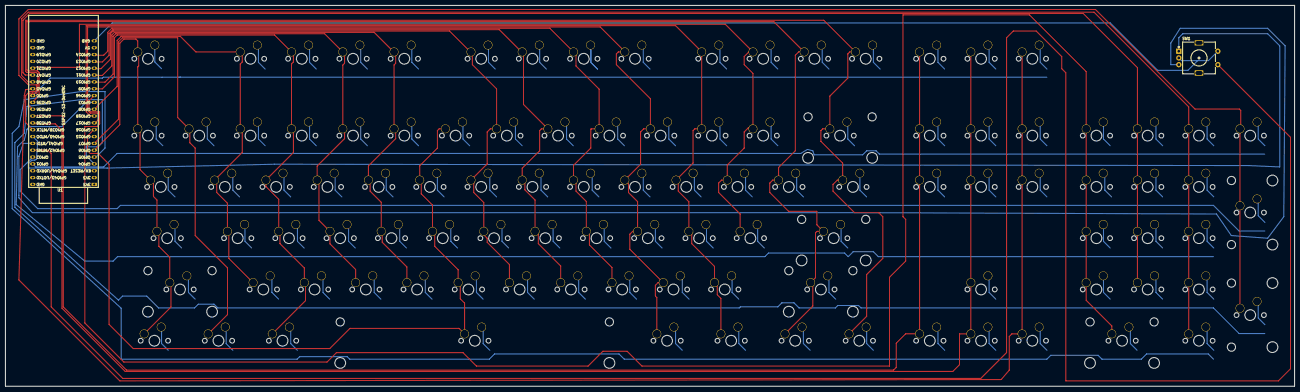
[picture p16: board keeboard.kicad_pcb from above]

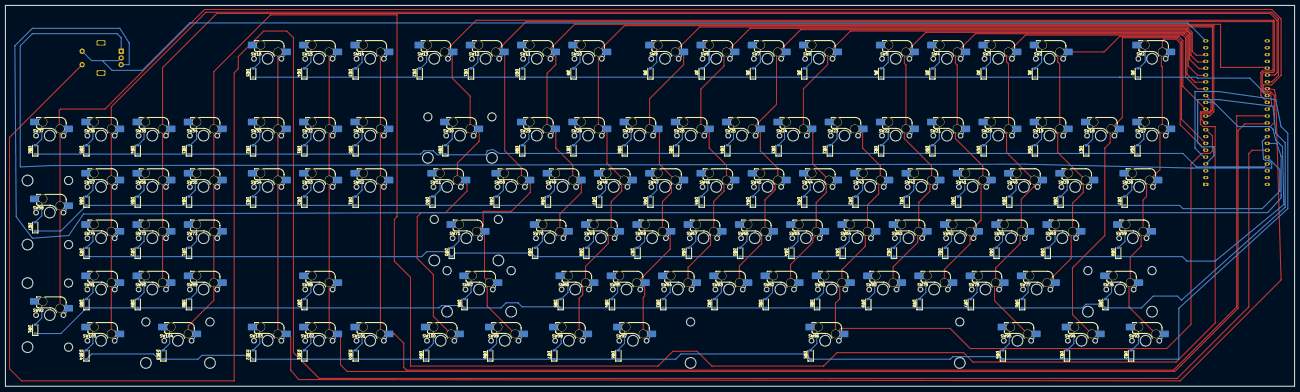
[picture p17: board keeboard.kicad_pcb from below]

Board: 2 copper layers, 479.0 x 141.5 mm, 218 parts (208 on the bottom side), 25 nets.

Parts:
D0, D1, D2, D3, D4, D5, D6, D7, D8, D9, D10, D11, D12, D13, D14, D15, D16, D17, D18, D19, D20, D21, D22, D23, D24, D25, D26, D27, D28, D29, D30, D31, D32, D33, D34, D35, D36, D37, D38, D39, D40, D41, D42, D43, D44, D45, D46, D47, D48, D49, D50, D51, D52, D53, D54, D55, D56, D57, D58, D59, D60, D61, D62, D63, D64, D65, D66, D67, D68, D69, D70, D71, D72, D73, D75, D76, D77, D78, D79, D80, D81, D82, D83, D84, D85, D86, D87, D88, D89, D90, D91, D92, D93, D94, D95, D96, D97, D98, D99, D100, D101, D102, D103, D104: 1N4148; D_SOD-123
S1, S2, S3, S4: MX_stab; STAB_MX_2u
S5, S8: MX_stab; STAB_MX_2.25u
S6: MX_stab; STAB_MX_2.75u
S7: MX_stab; STAB_MX_6.25u
SW1: RotaryEncoder_Switch; RotaryEncoder_Alps_EC11E-Switch_Vertical_H20mm
SW2, SW2#2, SW3, SW4, SW5, SW6, SW7, SW8, SW9, SW10, SW11, SW12, SW13, SW14, SW15, SW16, SW17, SW18, SW19, SW20, SW21, SW22, SW23, SW24, SW25, SW26, SW27, SW28, SW29, SW30, SW31, SW32, SW33, SW34, SW35, SW36, SW37, SW38, SW39, SW40, SW41, SW42, SW43, SW44, SW45, SW46, SW47, SW48, SW49, SW50, SW51, SW52, SW53, SW54, SW55, SW56, SW57, SW58, SW59, SW60, SW61, SW62, SW63, SW64, SW65, SW66, SW67, SW68, SW69, SW70, SW71, SW72, SW73, SW74, SW76, SW77, SW78, SW79, SW80, SW81, SW82, SW83, SW84, SW85, SW86, SW87, SW88, SW89, SW90, SW91, SW92, SW95, SW96, SW97, SW98, SW99, SW100, SW101, SW102, SW105: SW_Push; SW_MX_HS_CPG151101S11_1u
SW93, SW94, SW103, SW104: SW_Push; SW_MX_HS_CPG151101S11_1.25u
U1: ESP32-S3-DevKitC

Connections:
/COL0: SW2.1, SW60.1, SW93.1, U1.6 (GPIO6/ADC1_CH5)
/COL1: SW19.1, SW40.1, SW61.1, SW76.1, SW94.1, U1.7 (GPIO7/ADC1_CH6)
/COL2: SW3.1, SW20.1, SW41.1, SW62.1, SW77.1, SW95.1, U1.12 (GPIO8/ADC1_CH7)
/COL3: SW4.1, SW21.1, SW42.1, SW63.1, SW78.1, U1.15 (GPIO9/ADC1_CH8)
/COL4: SW5.1, SW22.1, SW43.1, SW64.1, SW79.1, U1.16 (GPIO10/ADC1_CH9)
/COL5: SW6.1, SW23.1, SW44.1, SW65.1, SW80.1, SW96.1, U1.17 (GPIO11/ADC2_CH0)
/COL6: SW7.1, SW24.1, SW45.1, SW66.1, SW81.1, U1.18 (GPIO12/ADC2_CH1)
/COL7: SW8.1, SW25.1, SW46.1, SW67.1, SW82.1, U1.19 (GPIO13/ADC2_CH2)
/COL8: SW9.1, SW26.1, SW47.1, SW68.1, SW83.1, U1.20 (GPIO14/ADC2_CH3)
/COL9: SW10.1, SW27.1, SW48.1, SW69.1, SW84.1, U1.10 (GPIO17/ADC2_CH6)
/COL10: SW11.1, SW28.1, SW49.1, SW70.1, SW85.1, SW97.1, U1.11 (GPIO18/ADC2_CH7)
/COL11: SW12.1, SW29.1, SW50.1, SW71.1, SW86.1, SW98.1, U1.27 (GPIO21)
/COL12: SW13.1, SW30.1, SW51.1, SW72.1, SW87.1, SW99.1, U1.32 (GPIO35)
/COL13: SW14.1, SW31.1, SW52.1, SW100.1, U1.33 (GPIO36)
/COL14: SW15.1, SW32.1, SW53.1, SW101.1, U1.34 (GPIO37)
/COL15: SW16.1, SW33.1, SW54.1, SW88.1, SW102.1, U1.35 (GPIO38)
/COL16: SW17.1, SW34.1, SW55.1, SW103.1, U1.30 (GPIO45)
/COL17: SW35.1, SW56.1, SW73.1, SW89.1, SW104.1, U1.14 (GPIO46)
/COL18: SW36.1, SW57.1, SW74.1, SW90.1, U1.28 (GPIO47)
/COL19: SW37.1, SW58.1, SW91.1, SW105.1, U1.29 (GPIO48)
/COL20: SW38.1, SW59.1, SW92.1, U1.36 (GPIO39/MTCK)
GND: SW1.C, SW1.S2, U1.22 (GND), U1.23 (GND), U1.24 (GND), U1.44 (GND)
unnamed: SW1.A, U1.37 (GPIO40/MTDO)
unnamed: SW1.B, U1.38 (GPIO41/MTDI)
unnamed: SW1.S1, U1.39 (GPIO42/MTMS)

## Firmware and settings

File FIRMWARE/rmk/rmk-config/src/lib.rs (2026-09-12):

use std::collections::HashMap;
use std::path::Path;

use config::{Config, File, FileFormat};
use serde::{Deserialize, de};
use serde_inline_default::serde_inline_default;

/// Event channel default configuration
const EVENT_DEFAULT_CONFIG: &str = include_str!("default_config/event_default.toml");

pub(crate) mod chip;
pub(crate) mod communication;
pub mod resolved;
#[rustfmt::skip]
pub mod usb_interrupt_map;
pub(crate) mod behavior;
pub(crate) mod board;
pub(crate) mod dfu;
pub(crate) mod display;
pub(crate) mod host;
pub(crate) mod keycode_alias;
pub(crate) mod keymap;
pub mod layout;
pub use layout::{STOCK_WIDTHS, layout_blob_from_toml, layout_info_from_toml};
pub(crate) mod light;
pub(crate) mod storage;

/// Protocol-level capacity ceilings for wire-format Vec sizes.
///
/// These define the maximum values any firmware may use for protocol
/// Vec capacities (`COMBO_SIZE`, `MORSE_SIZE`, etc.). The host tool compiles
/// against these as upper bounds. Any firmware with `rynk` enabled
/// must satisfy `value <= ceiling` at compile time.
///
/// Constant names mirror the generated constants with a `MAX_` prefix:
/// `COMBO_SIZE` is bounded by `MAX_COMBO_SIZE`, etc.
pub mod protocol_limits {
    /// Max keys in a combo trigger — ceiling for `COMBO_SIZE`
    pub const MAX_COMBO_SIZE: usize = 16;
    /// Max pattern entries per morse key — ceiling for `MORSE_SIZE`
    pub const MAX_MORSE_SIZE: usize = 32;
    /// Max bytes per macro data chunk — ceiling for `MACRO_DATA_SIZE`
    pub const MAX_MACRO_DATA_SIZE: usize = 256;
    /// Max key positions in an unlock challenge.
    pub const MAX_UNLOCK_KEYS_SIZE: usize = 4;
}

pub(crate) fn validate_unlock_keys(
    section: &str,
    unlock_keys: &[[u8; 2]],
    layout: Option<&LayoutTomlConfig>,
) -> Result<(), String> {
    if unlock_keys.len() > protocol_limits::MAX_UNLOCK_KEYS_SIZE {
        return Err(format!(
            "{section}.unlock_keys has {} entries, the max is {}",
            unlock_keys.len(),
            protocol_limits::MAX_UNLOCK_KEYS_SIZE
        ));
    }

    if let Some(layout) = layout {
        for key in unlock_keys {
            let (row, col) = (key[0], key[1]);
            if row >= layout.rows || col >= layout.cols {
                return Err(format!(
                    "{section}.unlock_keys position ({row}, {col}) is outside the {}x{} matrix",
                    layout.rows, layout.cols
                ));
            }
        }
    }

    Ok(())
}

/// Configurations for RMK keyboard.
#[derive(Clone, Debug, Deserialize)]
#[serde(deny_unknown_fields)]
#[allow(unused)]
pub struct KeyboardTomlConfig {
    /// Basic keyboard info
    keyboard: Option<KeyboardInfo>,
    /// Matrix of the keyboard, only for non-split keyboards
    matrix: Option<MatrixConfig>,
    // Aliases for key maps
    aliases: Option<HashMap<String, String>>,
    /// Keymap config: layer count and the per-layer key actions (`[[keymap.layer]]`).
    keymap: Option<KeymapTomlConfig>,
    /// Layout config: the physical key arrangement (`map`) plus the rendered layout.
    /// For split keyboards, the total row/col is defined in this section.
    layout: Option<LayoutTomlConfig>,
    /// Behavior config
    behavior: Option<BehaviorConfig>,
    /// Light config
    light: Option<LightConfig>,
    /// Storage config
    storage: Option<StorageConfig>,
    /// DFU partition config (embassy-boot)
    dfu: Option<DfuTomlConfig>,
    /// Ble config
    pub(crate) ble: Option<BleConfig>,
    /// Chip-specific configs (e.g., [chip.nrf52840])
    chip: Option<HashMap<String, ChipConfig>>,
    /// Dependency config
    dependency: Option<DependencyConfig>,
    /// Split config
    split: Option<SplitConfig>,
    /// Input device config
    input_device: Option<InputDeviceConfig>,
    /// Display config
    display: Option<DisplayConfig>,
    /// Output Pin config
    output: Option<Vec<OutputConfig>>,
    /// Set host configurations
    pub(crate) host: Option<HostConfig>,
    /// RMK config constants
    #[serde(default)]
    pub(crate) rmk: RmkConstantsConfig,
    /// Event channel configuration
    /// Default values are loaded from event_default.toml in new_from_toml_path()
    /// build.rs also loads event defaults via new_from_toml_path_with_event_defaults()
    #[serde(default)]
    pub(crate) event: EventConfig,
    /// Whether the user explicitly set a [storage] section in keyboard.toml.
    #[serde(skip)]
    pub(crate) storage_user_set: bool,
    /// Whether the user explicitly set `[storage]` `start_addr`/`num_sectors`
    /// in keyboard.toml (chip defaults don't count).
    #[serde(skip)]
    pub(crate) storage_start_addr_user_set: bool,
    #[serde(skip)]
    pub(crate) storage_num_sectors_user_set: bool,
    /// Whether the user explicitly wrote a [dfu] section in keyboard.toml
    /// (chip defaults contain an empty [dfu] too).
    #[serde(skip)]
    pub(crate) dfu_user_set: bool,
}
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

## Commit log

2026-07-18 Creating Schematic
    [keeboard.kicad_pcb, keeboard.kicad_sch]
2026-07-21 updating pcb stuff
    [keeboard.kicad_pcb, keeboard.kicad_sch]
2026-07-21 pcb edit & schematic
    [keeboard.kicad_pcb, keeboard.kicad_sch]
2026-08-01 Finishing up the pcb
    did all routing, wiring, etc...
    [freerouting.dsn, keeboard.kicad_pcb, keeboard.kicad_sch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]
2026-09-09 Updating folder and stuff
    [bottom.step, freerouting.dsn, keeboard.kicad_pcb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]
2026-09-11 Temporary AI readme
    Updated README.md to include project details, core architecture, bill of materials, case design, and cost tracking.
2026-09-11 Update diode specification to SMD type
2026-09-11 Add 3D printed case to hardware list
2026-09-11 Update switch description and cost in README
2026-09-11 Revise keycaps entry and add knob to hardware list
    Updated keycap description and cost, added 3D printed knob to hardware list.
2026-09-11 Add materials and links to README
2026-09-11 Revise diode details and add sourcing links
    Updated diode information with pricing and sourcing.
2026-09-12 firmware & cad files updated
    [Bottom.step, Top.step, partitions.csv]
2026-09-12 updaing firmware stuff
    [partitions.csv]
2026-09-14 Add 3D printed plate to materials list
    Added a new item for a 3D printed plate to the materials list.
2026-09-14 Revise component details and pricing in README
    Updated pricing and sources for various components, including PCB and foam sheet. Temporarily omitted silicone pour for budget considerations.
2026-09-14 Add esp32-s3-devkitc-1 to components list
2026-09-14 Refine README and update Bill of Materials
    Updated the README to remove temporary text, corrected BOM entries, and added missing items.
2026-09-15 Document KEEBoard project progress in JOURNAL.md
    Added detailed journal entries documenting the design and development process of the KEEBoard project, including PCB layout, component ordering, and soldering.
2026-09-15 Revise time logs and add new project updates
    Updated total time spent on various project stages and added new entries for design and component ordering.
2026-09-19 Revise README with project details and BOM
    Updated the README to include detailed project information, assembly instructions, and a comprehensive Bill of Materials (BOM) for the custom keyboard. Added sections for future improvements and gall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
2026-09-19 time to time updating files
    [bottom.stl, bottom_left.stl, bottom_right.stl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]
2026-09-19 Enhance README with gasket mount system description
    Added details about the custom gasket mount system and its design.
2026-09-19 Add BOM.csv with item details and costs
    Added a Bill of Materials (BOM) for the project with item details, costs, and links.
    [BOM.csv]
2026-09-19 adding PCB folder
    [1keeboard.csv, freerouting.dsn, keeboard.csv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]
2026-09-19 Document total time spent on case design
    Added total time spent for the task.
2026-09-21 Revise JOURNAL.md with project updates
    Updated journal entries detailing the progress on the mechanical keyboard project, including schematic updates, PCB design challenges, and case design considerations.
2026-09-25 Include CAD file link and upload explanation
    Added a link to an editable CAD file and noted upload reasons.
2026-09-25 Add entry for soldering Kailh Sockets
    Documented the process of soldering Kailh Sockets and included images.
2026-09-29 Document progress on PCB and keyboard case design
    Updated JOURNAL.md with various entries detailing progress on PCB and keyboard case design, including time spent on tasks and links to timelapse videos.
2026-09-30 Document progress on tiny diodes in JOURNAL.md
    Added a new entry about ongoing work with tiny diodes, including time spent and images.
2026-09-30 Revise journal entries for keyboard case design
    Updated journal entries for case design progress and adjustments.
2026-10-01 Update JOURNAL.md with diode soldering entry
    Documented completion of diode soldering and challenges faced.
2026-10-09 Update JOURNAL.md with recent keyboard project entries
    Documented progress on firmware research and keyboard assembly, including challenges faced and solutions implemented.
2026-10-09 Update JOURNAL.md with keyboard assembly details
    Documented progress on keyboard assembly, including soldering switches and stabilizers, and resolved issues with key functionality.
2026-10-10 Update JOURNAL.md with recent project progress
    Documented progress on heatsink screw installation and PORON gasket cutting. Added images and updated total time spent.
2026-10-15 Document print issues and redesign for top case
    Added entry for 10/14/2026 detailing issues with print and redesign efforts.
2026-10-17 Document installation of final case part
    Added details about the installation of the final part of the case, including the use of PORON gasket foam and adhesives.
2026-10-23 Update JOURNAL.md with firmware development notes
    Documented issues with ESP32-S3 pin usability and plans for a new development kit.
2026-10-24 Update journal entry for 10/22/2026
    Document issues with ESP32-S3 pins and screenshots not uploading.
2026-10-24 Document ESP32-S3 pin issues and setup experience
    Added details about issues with ESP32-S3 and setup process.
2026-10-27 Update journal entry for 10/26/2026
    Documented the challenges faced while desoldering and soldering ESP32 components, including time spent on the tasks.
2026-10-29 Update JOURNAL.md with recent project notes
    Document progress on fixing PCB routes and using insulated wires.
2026-10-29 Update JOURNAL.md with PCB repair details
    Documented the process of fixing PCB routes and using insulated wires. Included images and links to time-lapse videos.
2026-10-29 Revise time spent and document PCB repair process
    Updated total time spent on the project from 3.2 hours to 2.5 hours and documented the process of fixing PCB routes and soldering connections.
2026-11-04 Remove Future Improvements and update assembly steps
    Removed the Future Improvements section and updated assembly instructions.
